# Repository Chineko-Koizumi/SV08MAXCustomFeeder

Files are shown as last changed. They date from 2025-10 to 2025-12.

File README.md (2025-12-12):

# Description
Because original external feeder for Sovol SV08 MAX is (being direct) horrible I created this project to adress some issues. I treat this as self-development project so I not guaranteeing that it would work on your setup, but despite this I'm open to sugestions. For now everything is tested only on PLA setup.

# Quick look on setup

I did create my own extender for SV08 MAX so I can use whole 500mm of Z axis but if you do not use extender you need to measure how much height you lose. Not adjusting max height on not extended top may damage your printer!!! 
## Recording

https://www.youtube.com/watch?v=mHzhyefJMEk

## IRL photos
559814326_4341665236066659_7573989402878520107_n559183310_4341665459399970_7819196083902323529_n max-custom-feeder

## Models





## Tutorial
If you want just bare minimum you have to print custom enclosure for external feeder (in **ABS!!!** other materials would melt). Internal stepper motor gets realy hot and can overheat MCU.
### Hardware needed
* 8x M5 nuts and bolts(40mm)
* 5x threaded insert M3 5mm or 3mm
* 3x M3 bolt 12mm(or longer)
* 4x bearing 608 ZZ 8x22x7mm
* wooden countertop 800mmx400mmx18mm
* 1.5m of any cable capable of transfer power and signal to external feeder

### Step by step
#### Hardware
1) Before printing enclosure for external feeder use "BearingCheck.step" to test if model printed from your printer is a perfect fit, bearing must fit perfectly to ensure smooth filament passage. If not try to adjust offsets until bearings fit and apply them to the CustomFeederCase.step.

2) Print external feeder enclosure and handle in **ABS!!!**. Other materials would soften or worse even melt. Use supports for latches and overhangs.

3) Print every other part in PLA.

4) Those 2 elements might be lose, if so, apply some glue in socket 

5) Put 5 inserts according to images 

6) Drill contertop to allow mount of FeederMount.step, TopSpoolMount.step and TopDeckGlassMount.step, the suggested arangment is on photo below, mouting spool on the right shorten the length of PTFE tube. Assembly and mount parts.

7) To hold spool on rollers you can use anything cylindrical strong enough (I used curtain rod xD), but be aware that shaft may shift so aditional stoppers may be needed.

#### Software

1) In mainsail webpage replace original contents of buffer_stepper.cfg with the provided one.
2) Remove references to old buffer macros from Macro.cfg, example how to do it is inside example_Macro.cfg
3) There are 3 things inside buffer_stepper.cfg that may need adjustment:
   * variable_default_rotation_distance: 9.75 (this is rotation_distance in mm for buffer stepper recalculations)
   * variable_filament_length_ptfe: 1300.0 (this is length in mm between toolehad extruder and buffer)
4) Add INIT_CYCLIC_MACROS after CLEAR_PAUSE inside START_PRINT macro
5) Add CENTER_EXTERNAL_FEEDER after INIT_CYCLIC_MACROS
6) Add RESET_VARIABLES_BUFFER_STEPPER at the end of END_PRINT and CANCEL_PRINT macros

There is two modes in which filament buffer can operate:

- Passive: only filament runout sensor, I highly advise keep PTFE tube between buffer and toolhead but is not needed. **Spring/screw from handle pushing filament in buffer have to be removed to allow smooth passage!**
- Active: buffer (in mirror mode to toolhead) assist in filament feeding, PTFE tube between buffer and toolhead necessary.

Only one of them can be enabled at the same time, you have two comment out other one:
Sections in buffer_stepper.cfg: 

<pre>######################################################################
###### Active Filament Buffer                      
######################################################################</pre>

<pre>######################################################################
###### Passive Filament Buffer (filament sensor only)                         
######################################################################</pre>

# Versions

* V0.5
    * Better algorithm to find optimal rotation
    * Added step file handle with screw for better friction on filament
* V0.4
    * New working mode: "Passive"
    * Rotation calculation adjustment
* V0.3
    * Bug fix for frequent buffor rotation changes
* V0.2
    * New method for centering buffer, centering during print no longer needed

* V0.1
    * Initial macro for resynchronization
    * Initial macro for filament runout detectiom
    * Initial versions of step files for mod
      
Known issues

* V0.2
    * High flow rates triggers frequent buffor rotation changes
* V0.1
    * If for some reason filament inside buffer slips right after buffer recalculation, it will lead to big change in rotation and possibly constant recalculation those will block printing progress until method SET_BUFFER_DEFAULT_ROTATION_DISTANCE is called.

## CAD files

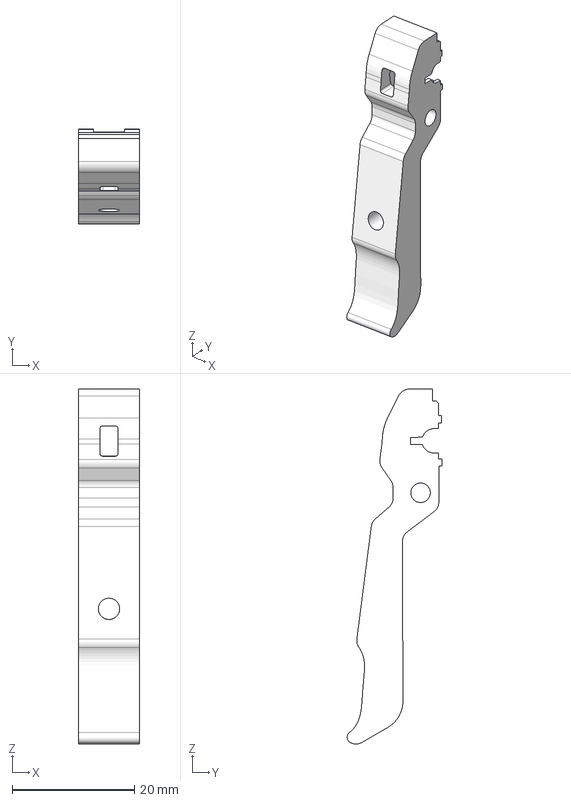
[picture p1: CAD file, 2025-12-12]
Handle.step
10.0 x 15.5 x 58.2 mm

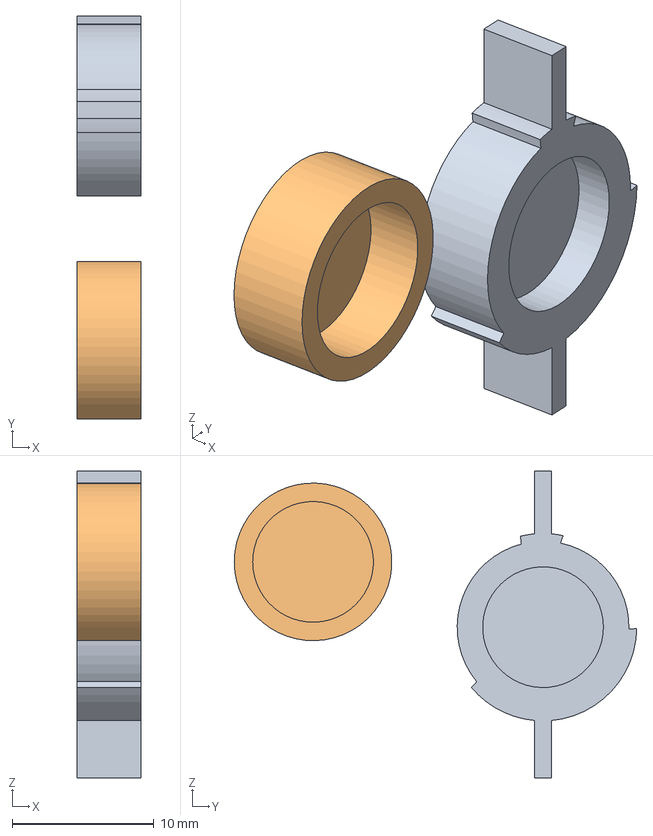
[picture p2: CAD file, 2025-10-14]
BearingCheck.step
4.50 x 28.3 x 21.6 mm

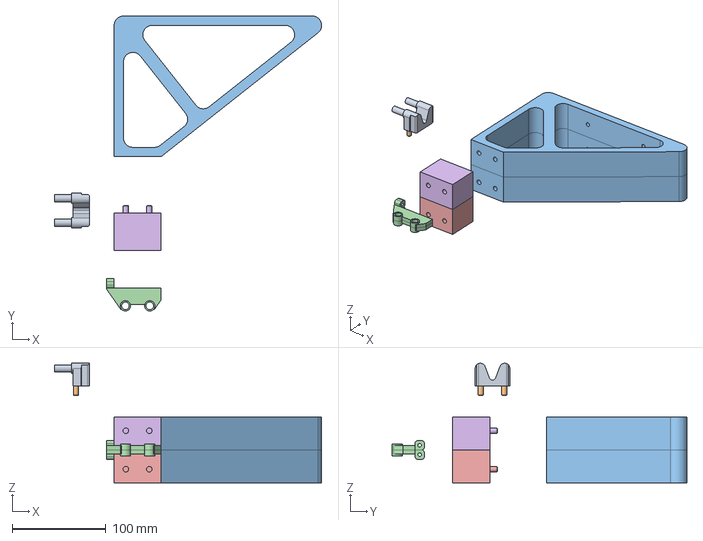
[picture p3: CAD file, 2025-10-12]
TopSpoolMount.step
284.9 x 314.5 x 127.5 mm

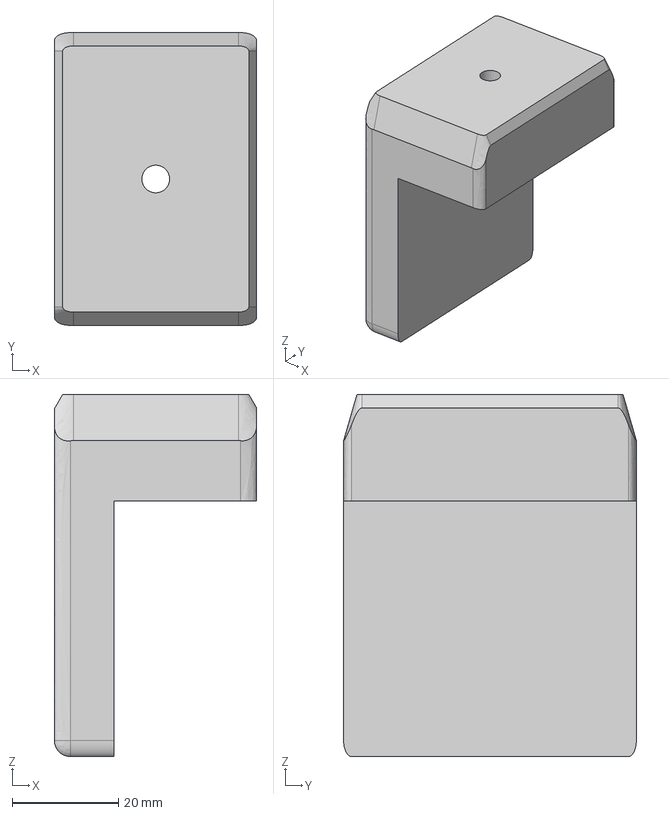
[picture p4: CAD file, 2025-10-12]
TopDeckGlassMount.step
38.0 x 55.0 x 68.0 mm

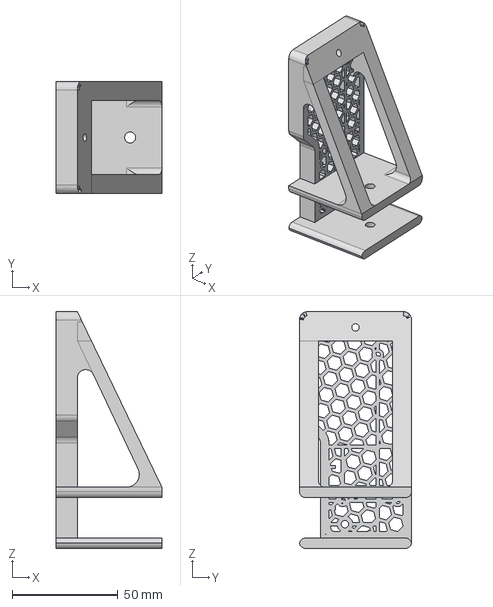
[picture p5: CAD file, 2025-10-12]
FeederMount.step
50.0 x 53.0 x 112.0 mm

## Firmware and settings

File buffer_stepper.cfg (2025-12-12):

[mcu buffer_mcu]
canbus_uuid: 704fe1305bd6

[gcode_macro variables]
variable_stop_feeding: False
gcode:

######################################################################
###### Default filament buffer config                             
######################################################################

#[buffer_stepper filament_buffer]
#step_pin: buffer_mcu: PA8           
#dir_pin: buffer_mcu: PA9           
#enable_pin: !buffer_mcu: PA11       
#microsteps: 16                      
#rotation_distance: 9.75               
#velocity: 150                        
#accel: 5000                         
#push_length: 25                  
#full_steps_per_rotation: 200   
#push_pin: ^buffer_mcu: PB11

#[tmc2209 buffer_stepper filament_buffer]
#uart_pin: buffer_mcu: PA12
#interpolate: True
#run_current: 0.9
#hold_current: 0.4
#sense_resistor: 0.150          
#uart_address: 3

######################################################################
######==========================================================######
######################################################################


#There is two modes in which filamnt bugffer can opperate:
#
# - Passive: only filament runout sensor, PTFE tube between buffer and toolhead not needed. Spring pushing have to be removed from buffer.  
# - Active: buffer (in mirror mode to toolhead) assist in fillament feeding, PTFE tube between buffer and toolheasd necessery

######################################################################
###### Active Filament Buffer                             
######################################################################

[extruder_stepper support_extra_stepper]
extruder: extruder
step_pin: buffer_mcu: PA8           
dir_pin: buffer_mcu: PA9           
enable_pin: !buffer_mcu: PA11   
microsteps: 16                      
rotation_distance: 9.75                                                                             
full_steps_per_rotation: 200

[tmc2209 extruder_stepper support_extra_stepper]
uart_pin: buffer_mcu: PA12
interpolate: True
run_current: 0.9
hold_current: 0.4
sense_resistor: 0.150          
uart_address: 3
[gcode_macro RESET_VARIABLES_BUFFER_STEPPER]
gcode:
    FEEDER_RESET_VARIABLES
    SENSOR_RESET_VARIABLES

[gcode_macro INIT_CYCLIC_MACROS]
gcode:
  SET_GCODE_VARIABLE MACRO=feeeder_variables VARIABLE=copy_rotation_distance VALUE={printer["gcode_macro feeeder_variables"].default_rotation_distance}
  
  UPDATE_DELAYED_GCODE ID=CYCLIC_MACROS DURATION=0.75

[delayed_gcode CYCLIC_MACROS]
gcode:
    CYCLIC_SENSOR_BUTTON_CHECK
    CYCLIC_BUFFER_BUTTON_CHECK

    UPDATE_DELAYED_GCODE ID=CYCLIC_MACROS DURATION=0.75

[gcode_macro CENTER_EXTERNAL_FEEDER] 
gcode:
    CENTER_EXTERNAL_FEEDER_IMPL

######################################################################
######==========================================================######
######################################################################

######################################################################
###### Passive Filament Buffer (filament sensor only)                          
######################################################################
#[gcode_macro RESET_VARIABLES_BUFFER_STEPPER]
#gcode:
#    SENSOR_RESET_VARIABLES
#
#[gcode_macro INIT_CYCLIC_MACROS]
#gcode:
#  
#  UPDATE_DELAYED_GCODE ID=CYCLIC_MACROS DURATION=1.0
#
#[delayed_gcode CYCLIC_MACROS]
#gcode:
#    CYCLIC_SENSOR_BUTTON_CHECK_PASSIVE
#
#    UPDATE_DELAYED_GCODE ID=CYCLIC_MACROS DURATION=1.0
#
#[gcode_macro CENTER_EXTERNAL_FEEDER] 
#gcode:

######################################################################
######==========================================================######
######################################################################

######################################################################
###### Feeder region                              
######################################################################
[gcode_macro feeeder_variables]
variable_is_set_feeder_stepper_initial_pos: False

variable_default_rotation_distance: 9.75
variable_index_count: 0.0
variable_half_distance: 0.0
variable_last_length_value: 0.0
variable_last_timestamp_value: 0 #in seconds for some reason cputime on my printer is fucking 1/25 second
variable_copy_rotation_distance: 9.75
variable_last_endstop_hit: 0 # 1 if last time end was hit, -1 if last time start was hit, 0 for initial center condition 

variable_start_hit_itteration: 0
variable_end_hit_itteration: 0


gcode:

[firmware_retraction]
retract_length: 0.8
#   The length of filament (in mm) to retract when G10 is activated,
#   and to unretract when G11 is activated (but see
#   unretract_extra_length below). The default is 0 mm.
retract_speed: 40
#   The speed of retraction, in mm/s. The default is 20 mm/s.
#unretract_extra_length: 0
#   The length (in mm) of *additional* filament to add when
#   unretracting.
unretract_speed: 20
#   The speed of unretraction, in mm/s. The default is 10 mm/s.

[gcode_macro BUFFER_MOVE]
gcode:
    FORCE_MOVE STEPPER="extruder_stepper support_extra_stepper" DISTANCE={params.VALUE|float} VELOCITY=50 ACCEL=2000
    M400

######################################################################
###### Centering feeder procedure                               
######################################################################

[gcode_macro CENTER_EXTERNAL_FEEDER_CHECK_BUTTON_END]
gcode:
    {% if not printer["gcode_button stall_push_end"].state == "PRESSED" %}
        BUFFER_MOVE VALUE=1
    {% endif %}

[gcode_macro CENTER_EXTERNAL_FEEDER_CHECK_BUTTON_START]
gcode:
    {% if not printer["gcode_button stall_push_start"].state == "PRESSED" %}
        SET_GCODE_VARIABLE MACRO=feeeder_variables VARIABLE=index_count VALUE={ printer["gcode_macro feeeder_variables"].index_count + 1.0 }
        BUFFER_MOVE VALUE=-1
    {% endif %}

[gcode_macro CENTER_EXTERNAL_FEEDER_EVALUATE]
gcode:
    {% set local_halfdistance = 1.0 * (printer["gcode_macro feeeder_variables"].index_count / 2.0) %}
    
    {% if printer["gcode_macro feeeder_variables"].index_count < 2.0 %}
      RESPOND PREFIX="INFO" MSG="CENTER_EXTERNAL_FEEDER: Check if fillament is inside external feeder. Then manualy run CENTER_EXTERNAL_FEEDER Macro."
      PAUSE
    {% else %}
      SET_GCODE_VARIABLE MACRO=feeeder_variables VARIABLE=half_distance VALUE={ local_halfdistance }
        
       BUFFER_MOVE VALUE={ local_halfdistance }
      
      SET_GCODE_VARIABLE MACRO=feeeder_variables VARIABLE=is_set_feeder_stepper_initial_pos VALUE=True
      RESPOND PREFIX="INFO" MSG="CENTER_EXTERNAL_FEEDER: calibrated center of external feeder."
      RESPOND PREFIX="INFO" MSG="{ "Half distance " + local_halfdistance|string + "mm"}"
    {% endif %}
    SET_GCODE_VARIABLE MACRO=feeeder_variables VARIABLE=index_count VALUE=0.0

[gcode_macro CENTER_EXTERNAL_FEEDER_IMPL] 
gcode:
    RESPOND PREFIX="INFO" MSG="CENTER_EXTERNAL_FEEDER: Calibration started."
    {% for x in range(0, 100): %} 
      CENTER_EXTERNAL_FEEDER_CHECK_BUTTON_END
    {% endfor %}

    {% for x in range(0, 100): %}
      CENTER_EXTERNAL_FEEDER_CHECK_BUTTON_START
    {% endfor %}

    CENTER_EXTERNAL_FEEDER_EVALUATE
######################################################################
######==========================================================######
######################################################################

######################################################################
###### Auto-calibration for feeeder rotation_distance                             
######################################################################
[gcode_macro FEEDER_RESET_VARIABLES]
gcode:
  SET_GCODE_VARIABLE MACRO=feeeder_variables VARIABLE=is_set_feeder_stepper_initial_pos VALUE=False

  SET_GCODE_VARIABLE MACRO=feeeder_variables VARIABLE=copy_rotation_distance VALUE={printer["gcode_macro feeeder_variables"].default_rotation_distance}
  SET_GCODE_VARIABLE MACRO=feeeder_variables VARIABLE=index_count VALUE=0.0
  SET_GCODE_VARIABLE MACRO=feeeder_variables VARIABLE=half_distance VALUE=0.0
  SET_GCODE_VARIABLE MACRO=feeeder_variables VARIABLE=last_length_value VALUE=0.0
  SET_GCODE_VARIABLE MACRO=feeeder_variables VARIABLE=last_endstop_hit VALUE=0 # 0 initial center, -1 start hit, 1 end hit
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

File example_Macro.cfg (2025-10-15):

[gcode_shell_command FACTORY_RESETS]
command: /home/sovol/factory_resets.sh
timeout: 2.

[force_move]
enable_force_move: True

[gcode_macro _global_var]
variable_pause_park:{'x': -2, 'y': -0.5, 'z': 10, 'e': 1}
variable_cancel_park:{'x': -2, 'y': 501, 'z': 10, 'e': 1}
variable_z_maximum_lifting_distance: 502
variable_pause_resume_travel_speed: 150
variable_load_filament_extruder_temp: 250
variable_bed_mesh_calibrate_target_temp: 65
variable_has_z_offset_calibrated: False
gcode:

[gcode_macro mainled_on]
gcode:
    SET_PIN PIN=main_led VALUE=1

[gcode_macro mainled_off]
gcode:
    SET_PIN PIN=main_led VALUE=0
    
[gcode_macro _IDLE_TIMEOUT]
gcode:
    {% if printer.print_stats.state == "paused" %}
      RESPOND TYPE=echo MSG="No operations in 30min!"
    {% else %}
     M84
     TURN_OFF_HEATERS
    {% endif %}

[gcode_macro _ALL_FAN_OFF]
gcode:
    M106 S0
    M107

[gcode_macro MOVE_TO_CENTER]
gcode:
    {% set x_offset = -19.8 %}
    {% set y_offset = -0.75 %}

    G28
    G91
    G1 X{x_offset} Y{y_offset}
    G90

[gcode_macro CLEAN_NOZZLE] 
gcode:
    BED_MESH_CLEAR
    {% if printer.toolhead.homed_axes != "xyz" %}
       G28
    {% endif %}
    M109 S200
    G90 
    G1 X30 Y195 F9000
    RUN_PROBE_VIR_CONTACT
    G91
    G1 Z3
    G90
    G1 X-7 F2400
    G91
    G1 Z-2.7
    G90
    G1 X-9 Y236
    G1 X-7 Y190 
    G1 X-9 Y225
    G1 X-7 Y205 
    G1 X-9 Y225
    G1 X-7 Y205
    G1 X-9 Y218
    G1 X-7 Y208
    G1 X-9 Y218
    G1 X-7 Y208
    G1 X-9 Y213
    G91
    G1 Z5
    G90
    G1 Y260 F9000
    G91 
    G1 Z-6.0
    G90
    G1 Y283 F2400
    G1 Y260
    G1 Y283
    M106 S255
    M109 S130
    M106 S0
    G1 Z10

[gcode_macro QUAD_GANTRY_LEVEL]
rename_existing:QUAD_GANTRY_LEVEL_BASE
gcode:
    {% if printer.toolhead.homed_axes|lower != "xyz" %}
        G28
    {% endif %}
    QUAD_GANTRY_LEVEL_BASE

[gcode_macro BED_MESH_CALIBRATE]
rename_existing: BED_MESH_CALIBRATE_BASE
gcode:
    {% set origin_square_corner_velocity_val = printer.toolhead.square_corner_velocity|float %}
    {% set temporarily_square_corner_velocity_val = 1.0 %}
    {% if not printer['gcode_macro _global_var'].has_z_offset_calibrated %}
        G28 X
        G28 Y
        Z_OFFSET_CALIBRATION METHOD=force_overlay BED_TEMP={printer.heater_bed.target}
    {% endif %}
    
    {% if printer.quad_gantry_level.applied|lower != 'true' %}
        QUAD_GANTRY_LEVEL
    {% endif %}
    SET_VELOCITY_LIMIT SQUARE_CORNER_VELOCITY={temporarily_square_corner_velocity_val}
    BED_MESH_CALIBRATE_BASE ADAPTIVE=1 PGP=0 METHOD=rapid_scan
    SET_VELOCITY_LIMIT SQUARE_CORNER_VELOCITY={origin_square_corner_velocity_val}

[gcode_macro START_PRINT]
gcode:
    CLEAR_PAUSE
    CLEAN_NOZZLE

    INIT_CYCLIC_MACROS
    CENTER_EXTERNAL_FEEDER
    
    SET_GCODE_OFFSET Z=0
    SET_VELOCITY_LIMIT ACCEL=40000 ACCEL_TO_DECEL=10000
    Z_OFFSET_CALIBRATION METHOD=force_overlay BED_TEMP={printer.heater_bed.target}
    SET_GCODE_VARIABLE MACRO=_global_var VARIABLE=has_z_offset_calibrated VALUE=True
    M400
    QUAD_GANTRY_LEVEL
    G28 Z
    BED_MESH_CALIBRATE
    SET_GCODE_VARIABLE MACRO=_global_var VARIABLE=has_z_offset_calibrated VALUE=False
    SET_PIN PIN=red_led VALUE=0
    SET_PIN PIN=blue_led VALUE=0
    M400
    #NOZZLE_CLOG_CHECK

[gcode_macro END_PRINT]
description: 
variable_state: 'normal'
gcode:
    {% set z_max = printer['gcode_macro _global_var'].z_maximum_lifting_distance|int %}
    {% set e_mintemp  = printer.configfile.settings['extruder'].min_extrude_temp %}
    {% if printer.toolhead.homed_axes|lower == "xyz" %}
        G91
        #{% if printer['filament_switch_sensor filament_sensor'].enable == True and printer['filament_switch_sensor filament_sensor'].filament_detected == True %}
        #    {% if (printer.extruder.target != 0 and printer.extruder.temperature >= printer.extruder.target) and printer.extruder.temperature >= e_mintemp %}
        #        G1 E-2 F2700
        #        G1 E-2 Z0.2 F2400
        #    {% endif %}
        #{% endif %}
        {% if (printer.gcode_move.position.z + 10) < z_max %}
            G1 Z+10 F3000
        {% else %}
            G1 Z+{(z_max - printer.gcode_move.position.z)} F3000
        {% endif %}
        G90
        G1 X-2 Y501 F9000
    {% endif %}
    _ALL_FAN_OFF
    TURN_OFF_HEATERS
    M220 S100
    M221 S100
    CLEAR_PAUSE
    #SET_GCODE_VARIABLE MACRO=_global_var VARIABLE=filament_sensor_print VALUE=False
    #CHECK_FILAMENT_STATUS

    RESET_VARIABLES_BUFFER_STEPPER
    
    M84 X Y Z E  
    {action_respond_info("Finish Print!")}

[gcode_macro CANCEL_PRINT]
description: 
rename_existing: CANCEL_PRINT_BASE
gcode:
    {% set x_park = printer['gcode_macro _global_var'].cancel_park.x|float %}
    {% set y_park = printer['gcode_macro _global_var'].cancel_park.y|float %}
    {% set z_park = printer['gcode_macro _global_var'].cancel_park.z|float %}
    {% set z_lift_max = printer['gcode_macro _global_var'].z_maximum_lifting_distance %}
    {% set e_restract = printer['gcode_macro _global_var'].cancel_park.e|float %}
    {% set e_mintemp  = printer.configfile.settings['extruder'].min_extrude_temp %}
    CANCEL_PRINT_BASE
    {% if printer.toolhead.homed_axes|lower == "xyz" %}
        G91
        #{% if printer['filament_switch_sensor filament_sensor'].enabled == True and printer['filament_switch_sensor filament_sensor'].filament_detected == True %}
        #    {% if (printer.extruder.target != 0 and printer.extruder.temperature >= printer.extruder.target) and printer.extruder.temperature >= e_mintemp %}
        #        G1 E-{e_restract} F500
        #    {% else %}
        #        {action_respond_info("Nozzle not hot enough")}
        #    {% endif %}
        #{% endif %}
        {%if (printer.gcode_move.position.z + 10) < z_lift_max %}
            G1 Z+10 F3000
        {% else %}
            G1 Z+{(z_lift_max - printer.gcode_move.position.z)} F3000
        {% endif %}
        G90
        G1 X{x_park} Y{y_park} F9000
    {% endif %}
    TURN_OFF_HEATERS
    _ALL_FAN_OFF
    CLEAR_PAUSE
    #SET_GCODE_VARIABLE MACRO=_global_var VARIABLE=filament_sensor_print VALUE=False
    #CHECK_FILAMENT_STATUS

    RESET_VARIABLES_BUFFER_STEPPER
    
    M220 S100
    M221 S100
    M84
    {action_respond_info("Cancel Print Success!")}
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

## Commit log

2025-10-12 V0.1 step files for mod
    [FeederMount.step, TopAcrylicFrontBack3mm.dxf, TopAcrylicRightLeft3mm.dxf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]
2025-10-12 V0.1 initial macros
    [buffer_stepper.cfg]
2025-10-12 Update buffer_stepper.cfg
    Bug fix
    [buffer_stepper.cfg]
2025-10-14 tutorial corrections
    [BearingCheck.step, example_Macro.cfg]
2025-10-15 unknown command fix
    [buffer_stepper.cfg]
2025-10-15 example macro supplement
    [example_Macro.cfg]
2025-10-15 removal of not needed files
    [TopAcrylicFrontBack3mm.dxf, TopAcrylicRightLeft3mm.dxf, TopFlatAcrylic8mm.dxf]
2025-10-15 V0.2 new mechanism for recalculation, no more centring, retraction and stopping prints
    [buffer_stepper.cfg]
2025-10-17 V0.3 bug fix for excessive rotation recalculations on high flow rates
    [buffer_stepper.cfg]
2025-11-10 v0.4 passive filament sensor, buffer rotation correction adjustment
    [buffer_stepper.cfg]
2025-12-12 V0.5 algorthm adjustment, new handle for buffer
    [Handle.step, buffer_stepper.cfg]
